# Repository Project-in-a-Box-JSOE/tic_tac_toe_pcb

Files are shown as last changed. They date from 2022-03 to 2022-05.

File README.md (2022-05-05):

# Tic-Tac-Toe

**A project series hosted by Project in a Box at UCSD**
> Workshop documentation [Tic-Tac-Toe Guide](https://docs.google.com/presentation/d/1Ihq2s2tMd88KeOKXIFUcY-OSz5jwRyJ442QZBEG7MqE/edit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)<br />
> More about [Project in a Box](https://pibucsd.org/)

## Overview
This workshop is oriented to assembling a handheld Tic-Tac-Toe board with surface mount devices (SMD) and reflow soldering.

The PCB was designed in Autodesk EAGLE

## BOM

| Component | Vendor | Quantity |
| --- | --- | --- |
| NeoPixel Reverse Mount LEDs  | [Digikey](https://www.digikey.com/en/products/detail/adafruit-industries-llc/4960/14302512) | 9 |
| ATMEGA328P-AUR | [Digikey](https://www.digikey.com/en/products/detail/microchip-technology/ATMEGA328P-AUR/2357086) | 1 |
| Tactile SMD Switch | [Digikey](https://www.digikey.com/en/products/detail/te-connectivity-alcoswitch-switches/FSMSMTR/529671) | 10 | 
| 5V-Regulator NCP1117ST50T3G  | [Digikey](https://www.digikey.com/en/products/detail/onsemi/NCP1117ST50T3G/1967217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) | 1 | 
| Male Header (2x3-pins) | [Digikey](https://www.digikey.com/en/products/detail/sullins-connector-solutions/PREC003DAAN-RC/2774891) | 1 |
| DC Power Jack Socket | [Digikey](https://www.digikey.com/en/products/detail/cui-devices/PJ-102AH/408448) | 1 |
| 330Ω SMD Resistor | [Digikey](https://www.digikey.com/en/products/detail/yageo/RC1206FR-07330RL/731769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) | 1 |
| 10kΩ SMD Resistor | [Digikey](https://www.digikey.com/en/products/detail/bourns-inc/CR0805-FX-1002ELF/3592928) | 1 |
| 0.1uF Ceramic SMD Capacitor  | [Digikey](https://www.digikey.com/en/products/detail/kyocera-avx/08055F104K4T2A/1024871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) | 3 |
| 4.7uF Ceramic SMD Capacitor  | [Digikey](https://www.digikey.com/en/products/detail/samsung-electro-mechanics/CL21A475KAQNNNE/3886902) | 1 |
| 10uF Tantalum SMD Capacitor  | [Digikey](https://www.digikey.com/en/products/detail/kyocera-avx/TAJR106M006RNJ/808827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) | 2 |
| 22pF Ceramic SMD Capacitor  | [Digikey](https://www.digikey.com/en/products/detail/kemet/C0805C220J5GACTU/411388) | 2 |
| 16MHz SMD Cystal  | [Digikey](https://www.digikey.com/en/products/detail/ecs-inc/ECS-160-12-33-AGN-TR/9648827) | 1 |
| TicTacToe PCB  | [JLCPCB](https://jlcpcb.com/) | 1 |

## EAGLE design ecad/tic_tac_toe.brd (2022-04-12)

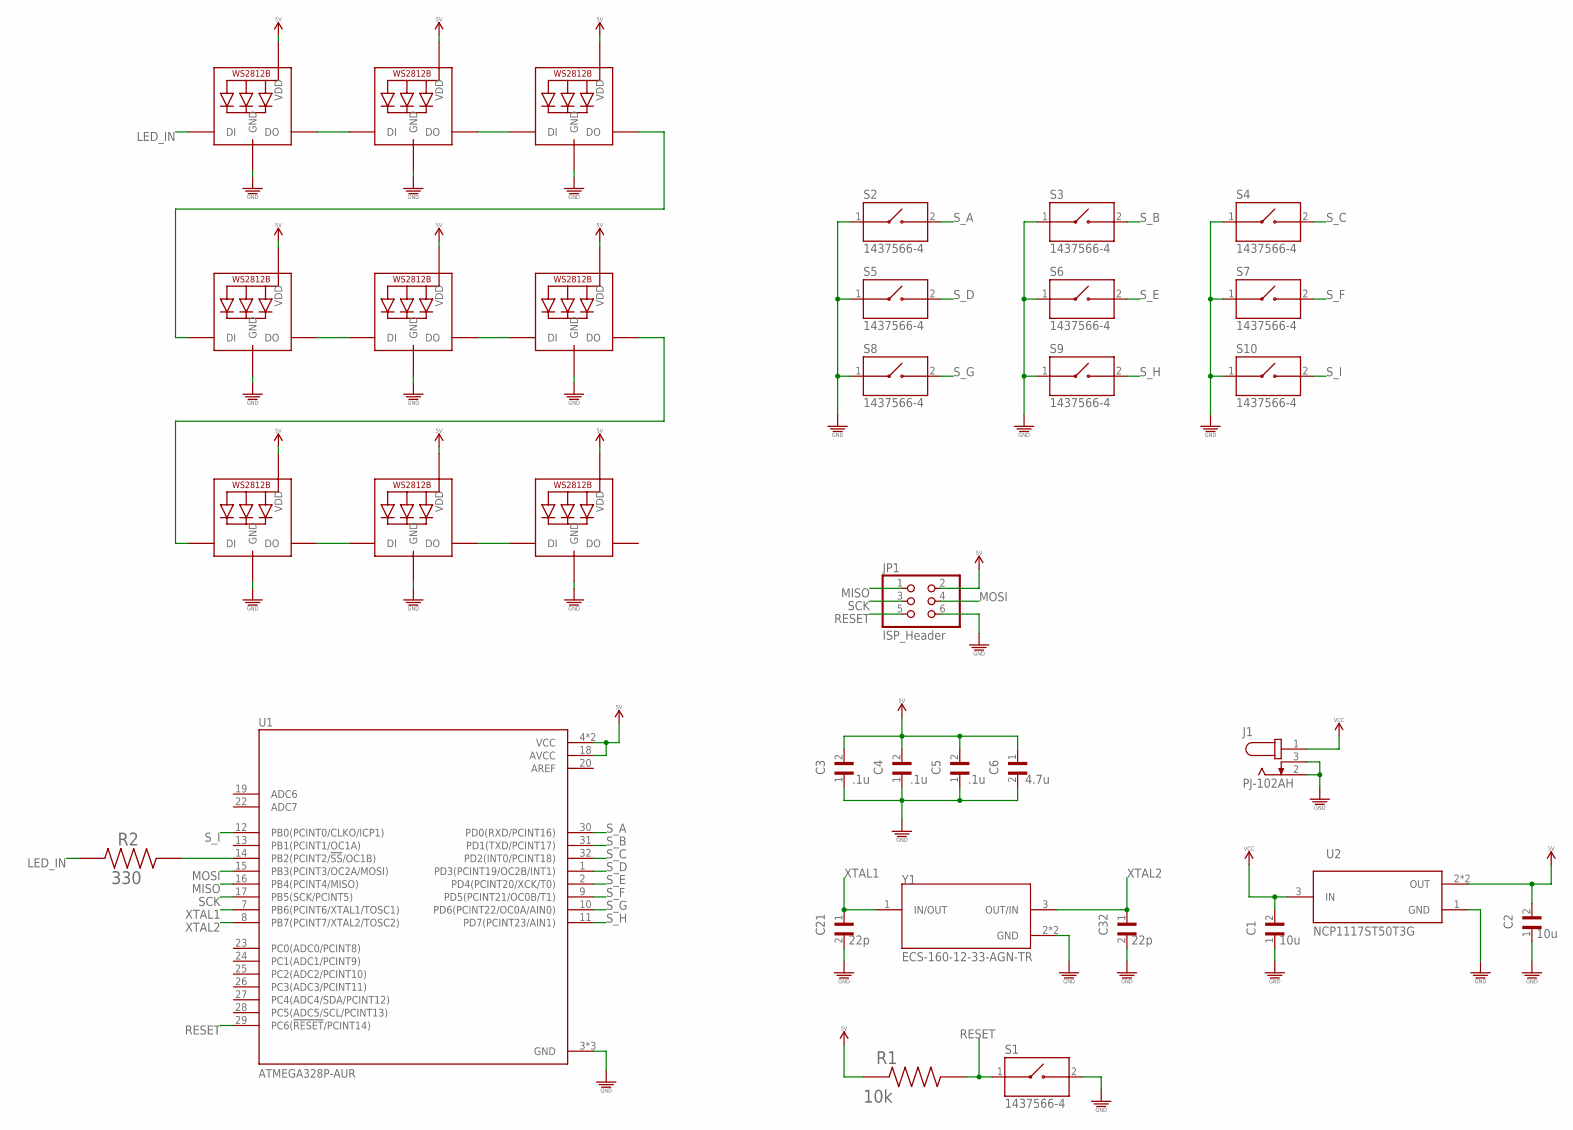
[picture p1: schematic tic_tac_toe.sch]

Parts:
C1, C2: 10u; CAPC2012X140N
C3, C4, C5: .1u; CAPC2012X140N
C6: 4.7u; CAPC2012X140N
C21, C32: 22p; CAPC2012X140N
J1: PJ-102AH; CUI_PJ-102AH
JP1: ISP_Header; 2X03
LED1, LED2, LED3, LED4, LED5, LED6, LED7, LED8, LED9: MICROBUILDER_WS2812B_SK6812E; MICROBUILDER_NEO3535_REVERSE
R1: 10k; RESC2012X60N
R2: 330; RESC3116X65N
S1, S2, S3, S4, S5, S6, S7, S8, S9, S10: 1437566-4; SW_1437566-4
U1: ATMEGA328P-AUR; QFP80P900X900X120-32N
U2: NCP1117ST50T3G; SOT230P700X180-4N
Y1: ECS-160-12-33-AGN-TR; XTAL_ECS-160-12-33-AGN-TR

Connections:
5V: C2.2, C3.2, C4.2, C5.2, C6.1, JP1.2, LED1.1-VDD (VDD), LED2.1-VDD (VDD), LED3.1-VDD (VDD), LED4.1-VDD (VDD), LED5.1-VDD (VDD), LED6.1-VDD (VDD), LED7.1-VDD (VDD), LED8.1-VDD (VDD), LED9.1-VDD (VDD), R1.1, U1.4 (VCC), U1.6 (VCC), U1.18 (AVCC), U2.2 (OUT), U2.4 (OUT)
AREF: U1.20 (AREF)
GND: C1.1, C2.1, C3.1, C4.1, C5.1, C6.2, C21.2, C32.2, J1.2, J1.3, JP1.6, LED1.3-GND (GND), LED2.3-GND (GND), LED3.3-GND (GND), LED4.3-GND (GND), LED5.3-GND (GND), LED6.3-GND (GND), LED7.3-GND (GND), LED8.3-GND (GND), LED9.3-GND (GND), S1.2, S2.1, S3.1, S4.1, S5.1, S6.1, S7.1, S8.1, S9.1, S10.1, U1.3 (GND), U1.5 (GND), U1.21 (GND), U2.1 (GND), Y1.2 (GND), Y1.4 (GND)
LED_IN: LED1.4-DIN (DI), R2.1
MISO: JP1.1, U1.16 (PB4(PCINT4/MISO))
MOSI: JP1.4, U1.15 (PB3(PCINT3/OC2A/MOSI))
unnamed: R2.2, U1.14 (PB2(PCINT2/!SS!/OC1B))
unnamed: LED1.2-DOUT (DO), LED2.4-DIN (DI)
unnamed: LED2.2-DOUT (DO), LED3.4-DIN (DI)
unnamed: LED4.2-DOUT (DO), LED5.4-DIN (DI)
unnamed: LED5.2-DOUT (DO), LED6.4-DIN (DI)
unnamed: LED7.2-DOUT (DO), LED8.4-DIN (DI)
unnamed: LED8.2-DOUT (DO), LED9.4-DIN (DI)
unnamed: LED3.2-DOUT (DO), LED4.4-DIN (DI)
unnamed: LED6.2-DOUT (DO), LED7.4-DIN (DI)
RESET: JP1.5, R1.2, S1.1, U1.29 (PC6(!RESET!/PCINT14))
SCK: JP1.3, U1.17 (PB5(SCK/PCINT5))
S_A: S2.2, U1.30 (PD0(RXD/PCINT16))
S_B: S3.2, U1.31 (PD1(TXD/PCINT17))
S_C: S4.2, U1.32 (PD2(INT0/PCINT18))
S_D: S5.2, U1.1 (PD3(PCINT19/OC2B/INT1))
S_E: S6.2, U1.2 (PD4(PCINT20/XCK/T0))
S_F: S7.2, U1.9 (PD5(PCINT21/OC0B/T1))
S_G: S8.2, U1.10 (PD6(PCINT22/OC0A/AIN0))
S_H: S9.2, U1.11 (PD7(PCINT23/AIN1))
S_I: S10.2, U1.12 (PB0(PCINT0/CLKO/ICP1))
VCC: C1.2, J1.1, U2.3 (IN)
XTAL1: C21.1, U1.7 (PB6(PCINT6/XTAL1/TOSC1)), Y1.1 (IN/OUT)
XTAL2: C32.1, U1.8 (PB7(PCINT7/XTAL2/TOSC2)), Y1.3 (OUT/IN)

Board: 2 copper layers, 34 parts (0 on the bottom side), 28 nets, no tracks yet.

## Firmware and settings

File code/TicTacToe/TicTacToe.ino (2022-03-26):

#include <FastLED.h>

#define NUM_LEDS 9
#define DATA_PIN 6
#define CHIPSET NEOPIXEL
#define BUTTON1 A0
#define BUTTON2 A1
#define BUTTON3 A2
#define BUTTON4 A3
#define BUTTON5 A4
#define BUTTON6 A5
#define BUTTON7 10
#define BUTTON8 9
#define BUTTON9 8
#define BUTTON_RESET 7
#define LED1 -1
#define LED2 -1
#define LED3 -1
#define LED4 -1
#define LED5 -1
#define LED6 -1
#define LED7 -1
#define LED8 -1
#define LED9 -1
#define RED CRGB::Red
#define BLUE CRGB::Blue
#define BLACK CRGB(0x000000)
#define BRIGHTNESS 50

bool newGame = true;
unsigned int userInput = -1;
bool player1sTurn = false;
CRGB leds[NUM_LEDS];
int buttons[] = {BUTTON1, BUTTON2, BUTTON3,
                 BUTTON4, BUTTON5, BUTTON6,
                 BUTTON7, BUTTON8, BUTTON9,
                 BUTTON_RESET};
int buttonStates[] = {0,0,0,
                      0,0,0,
                      0,0,0,0};
int theLEDs[] = {LED1, LED2, LED3,
                 LED4, LED5, LED6,
                 LED7, LED8, LED9};
int numButtons = 10;
int numLEDs = 9;
int winningLEDs[] = {-1,-1,-1};

void setup() {
  // put your setup code here, to run once:
  pinMode(BUTTON1, INPUT_PULLUP);
  pinMode(BUTTON2, INPUT_PULLUP);
  pinMode(BUTTON3, INPUT_PULLUP);
  pinMode(BUTTON4, INPUT_PULLUP);
  pinMode(BUTTON5, INPUT_PULLUP);
  pinMode(BUTTON6, INPUT_PULLUP);
  pinMode(BUTTON7, INPUT_PULLUP);
  pinMode(BUTTON8, INPUT_PULLUP);
  pinMode(BUTTON9, INPUT_PULLUP);
  pinMode(BUTTON_RESET, INPUT_PULLUP);
  Serial.begin(9600);
  FastLED.addLeds<CHIPSET, DATA_PIN>(leds, NUM_LEDS);
  FastLED.setBrightness(BRIGHTNESS);
  startUp();
}

void startUp() {
  for(int i = 0; i < NUM_LEDS; i++) {
    if(i != 0) {
      leds[i-1] = BLACK;
    }
    leds[i] = CRGB::Purple;
    FastLED.show();
    delay(100);
  }
  leds[NUM_LEDS - 1] = BLACK;
  FastLED.show();
}

void loop() {
  // put your main code here, to run repeatedly:
  if(newGame) {
    playGame();
  }
}

void playGame() {
  int roundResult = -1;
  int stateOfGame = 0;
  int numRounds = 0;
  bool reachedLastRound = false;
  while(!stateOfGame) {
    if(!reachedLastRound) {
      roundResult = playRound();
    }
    
    if(roundResult == -2) {
      newGame = true;
      break;
    }
    stateOfGame = checkStateOfGame(roundResult, reachedLastRound);
    reachedLastRound = ((numRounds>=8)?true:false);
    numRounds++;
  }
  switch(stateOfGame) {
    case 0:
      finishGame(false);
      break;
    case 1:
      finishGame(true);
      break;
    case 2:
      tieGame();
  }
}

int checkStateOfGame(int playerMove, bool thereIsTie) {
  // Check tie first
  if(thereIsTie) {
    return 2;
  }
  // If playerMove in {1,3,5,7,9} (odd), check diagonal
  // Always check column/row
  int playerNum = buttonStates[playerMove];
  if((playerMove)%2==0) { // checking for evens because playerMove is index
    return (checkDiagonalWin(playerMove,playerNum) || checkRow(playerMove,playerNum) || checkColumn(playerMove,playerNum));
  }
  
  return (checkRow(playerMove,playerNum) || checkColumn(playerMove,playerNum));
}

bool checkDiagonalWin(int playerMove,int playerNum) {
  if(playerMove == 1 || playerMove == 9) {
    return checkRDiag(playerMove, playerNum);
  }
  else if(playerMove == 3 || playerMove == 7) {
    return checkLDiag(playerMove, playerNum);
  }
  else {
    return (checkRDiag(playerMove, playerNum) || checkLDiag(playerMove, playerNum));
  }
}

bool checkRDiag(int playerMove, int playerNum) {
  int ledOne = buttonStates[0];
  winningLEDs[0] = 0;
  winningLEDs[1] = 4;
  winningLEDs[2] = 8;
  return ((ledOne==playerNum)&&(ledOne==buttonStates[4])&&(ledOne==buttonStates[8]));
}

bool checkLDiag(int playerMove, int playerNum) {
  int ledThree = buttonStates[2];
  winningLEDs[0] = 2;
  winningLEDs[1] = 4;
  winningLEDs[2] = 6;
  return ((ledThree==playerNum)&&(ledThree==buttonStates[4])&&(ledThree==buttonStates[6]));
}

bool checkRow(int playerMove, int playerNum) {
  int row = playerMove / 3;
  for(int i = (row*3);i<(row*3+3);i++) {
    if(buttonStates[i] != playerNum) {
      return false;
    }
  }
  winningLEDs[0] = row*3;
  winningLEDs[1] = row*3+1;
  winningLEDs[2] = row*3+2;
  return true;
}

bool checkColumn(int playerMove, int playerNum) {
  int col = playerMove % 3;
  for(int i = col; i<9; i+=3) {
    if(buttonStates[i]!=playerNum) {
      return false;
    }
  }
  winningLEDs[0] = col;
  winningLEDs[1] = col+3;
  winningLEDs[2] = col+6;
  return true;
}

void tieGame() {
  CRGB theLEDColors[9];
  for(int i = 0; i<9; i++) {
    theLEDColors[i] = leds[i];
    setLED(i,BLACK);
  }
  FastLED.show();
  for(int j = 0; j<5; j++) {
    delay(100);
    for(int i = 0; i<9; i++) {
      setLED(i,theLEDColors[i]);
    }
    FastLED.show();
    delay(200);
    for(int i = 0; i<9; i++) {
      setLED(i,BLACK);
    }
    FastLED.show();
  }
  for(int i = 0; i<9; i++) {
    setLED(i,theLEDColors[i]);
  }
  FastLED.show();
  finishGame(false);
}

void finishGame(bool gameHasWinner) {
  Serial.println("finishGame called");
  if(gameHasWinner) {
    flashWinnerLights();
  }
  startUp();
  turnOffLEDs(); 
  for(int i = 0; i < 10; i++) {
    buttonStates[i] = 0;
  }
}

void flashWinnerLights() {
  // Try to write a better algorithm for this,
  // I'm brain dead rn
  int winnerNum = player1sTurn ? 2 : 1;
  CRGB winnerColor = player1sTurn ? BLUE : RED;
  //int winnerLEDs[] = {-1,-1,-1,-1,-1};
  // If there is a winner, there should be a max
  // possible # of moves by the winner of 5
  int numWinningLEDs = 0;
  /*for(int i = 0; i < numButtons; i++) {
    if(buttonStates[i]==winnerNum) {
      winnerLEDs[numWinningLEDs]=i;
      numWinningLEDs++;
    }
  }*/
  numWinningLEDs = 3;
  for(int i = 0; i < 3; i++) {
    Serial.print(winningLEDs[i]);
    Serial.print(" ");
  }
  Serial.println();
  for(int i = 0; i < 5; i++) {
    for(int j = 0; j < numWinningLEDs; j++) {
      setLED(winningLEDs[j], winnerColor);
    }
    FastLED.show();
    delay(200);
    for(int j = 0; j < numWinningLEDs; j++) {
      setLED(winningLEDs[j], BLACK);
    }
    FastLED.show();
    delay(100);
  }
}

void turnOffLEDs() {
  for(int i = 0; i < numLEDs; i++) {
    if(leds[i] == BLACK) {
      continue;
    }
    leds[i] = BLACK;
    FastLED.show();
    delay(100); // To give the turning off more of an animated feel
  }
}

int playRound() {
  userInput = waitForUserInput();
  if(buttons[userInput] == BUTTON_RESET) {
    Serial.println("Button reset pressed");
    return -2;
  }
  lightUpLED(player1sTurn, userInput);
  flipUserTurn();
  return userInput;
}


void flipUserTurn() {
  player1sTurn = !player1sTurn;
}

int waitForUserInput() {
  int theUserInput = getUserInput();
  int counter = 0;
  String a = "Waiting for input ";
  while(theUserInput == -1) {
    //a = a.substring(0,a.indexOf(' ',15));
    //a.concat(counter);
    a = a + counter++;
    for(int i = 0; i < 10; i++) {
      Serial.print(buttonStates[i]);
      Serial.print(" ");
    }
    Serial.println();
    theUserInput = getUserInput();
    //counter += 1;
    delay(10);
  }
  Serial.println("Out of input");
  return theUserInput;
}

int getUserInput() {
  for(int i = 0; i < numButtons; i++) {
    if(digitalRead(buttons[i]) == LOW) {
      if(buttonStates[i] == 1 || buttonStates[i] == 2) {
        Serial.print("Already pressed:");
        Serial.println(i);
        return -1;
      }
      Serial.print("User input: ");
      Serial.println(i);
      return i;
    }
  }
  return -1;
}

void lightUpLED(bool itsPlayer1sTurn, int userInput) {
  if(itsPlayer1sTurn) {
    buttonStates[userInput] = 1;
    setLED(userInput,RED);
  }
  else {
    buttonStates[userInput] = 2;
    setLED(userInput,BLUE);
  }
  FastLED.show();
}

void setLED(int userInput, CRGB color) {
  leds[userInput] = color;
}

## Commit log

2022-03-25 ecad, gerbers
    [tic_tac_toe.brd, tic_tac_toe.sch]
2022-04-12 v3 sch
    [tic_tac_toe.brd, tic_tac_toe.sch]
2022-04-12 readme BOM
